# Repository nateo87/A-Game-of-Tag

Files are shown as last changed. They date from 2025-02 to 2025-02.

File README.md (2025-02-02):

# A Game of Tag
Here's the first genuine game project from David L Heiserman's 1978 book "How to Design & Build Your Own Custom TV Games". It's a very simple game where two player squares are moved around the screen. When one square touches another, both players disappear from the screen (it's up to you to decide who is "it"). Originally even less complex, I opted to add a little beep sound for when the tag occurs. The pitch of the beep can be set with a jumper on the upper-right side of the board.

It's easy for the player charcaters to fly off the screen - I recommend marking on your potentiometer knobs a sort of "starting position". Anyways, I encourage you to take a look into the book and tweak the designs. There's one addition the book recommends that would add "inertia" to the moving squares! Have fun, and please don't hesitate to reach out with questions.

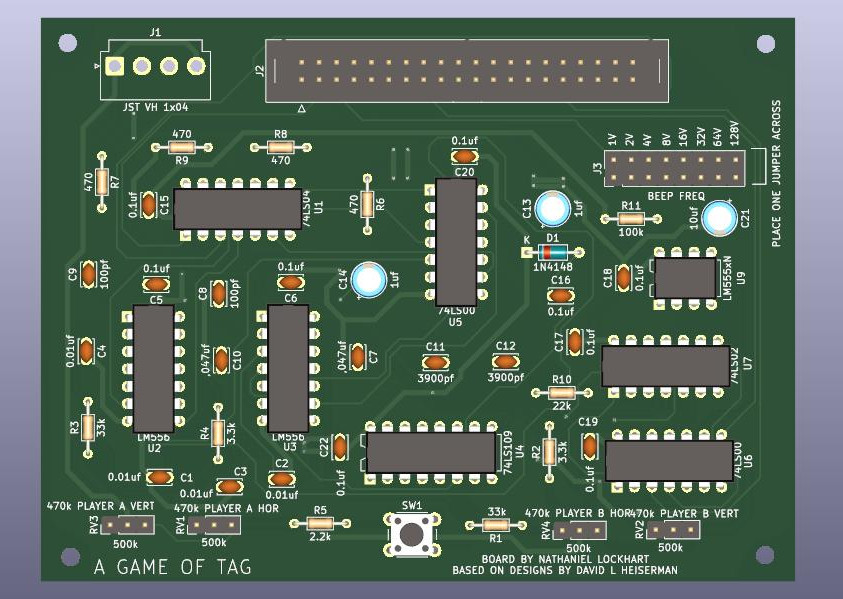
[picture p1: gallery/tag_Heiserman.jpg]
board render from KiCad


You can just solder wires directly from your player control pots to the PCB, or you can use pinheaders and have wires going from the pots with crimped on molex connectors at the other end. 

<b> BOM </b>

Caps:<br>
100pf x 2<br>
3900pf x 2<br>
10nf x 4<br>
47nf x 2<br>
0.1uf x 9<br>

Elec. Caps:<br>
1uf x 2<br>
10uf x 1<br>

Resistors:<br>
470ohm x 4<br>
2.2k x 1<br>
3.3k x 2<br>
22k x 1<br>
33k x 2<br>
100k x 1<br>

Potentiometers:<br>
500k x 4

Diode:<br>
1N4148 x 1

Switch:<br>
6x6mm tact switch x 1

Pin headers:<br>
2x20 IDC male, 2.54mm pitch<br>
2x8 pin header, 2.54mm pitch<br>
1x3 pin header, 2.54mm pitch x 4<br>

ICs:<br>
74LS00 x 2<br>
74LS02<br>
74LS04<br>
74LS109<br>
LM555<br>
LM556 x 2

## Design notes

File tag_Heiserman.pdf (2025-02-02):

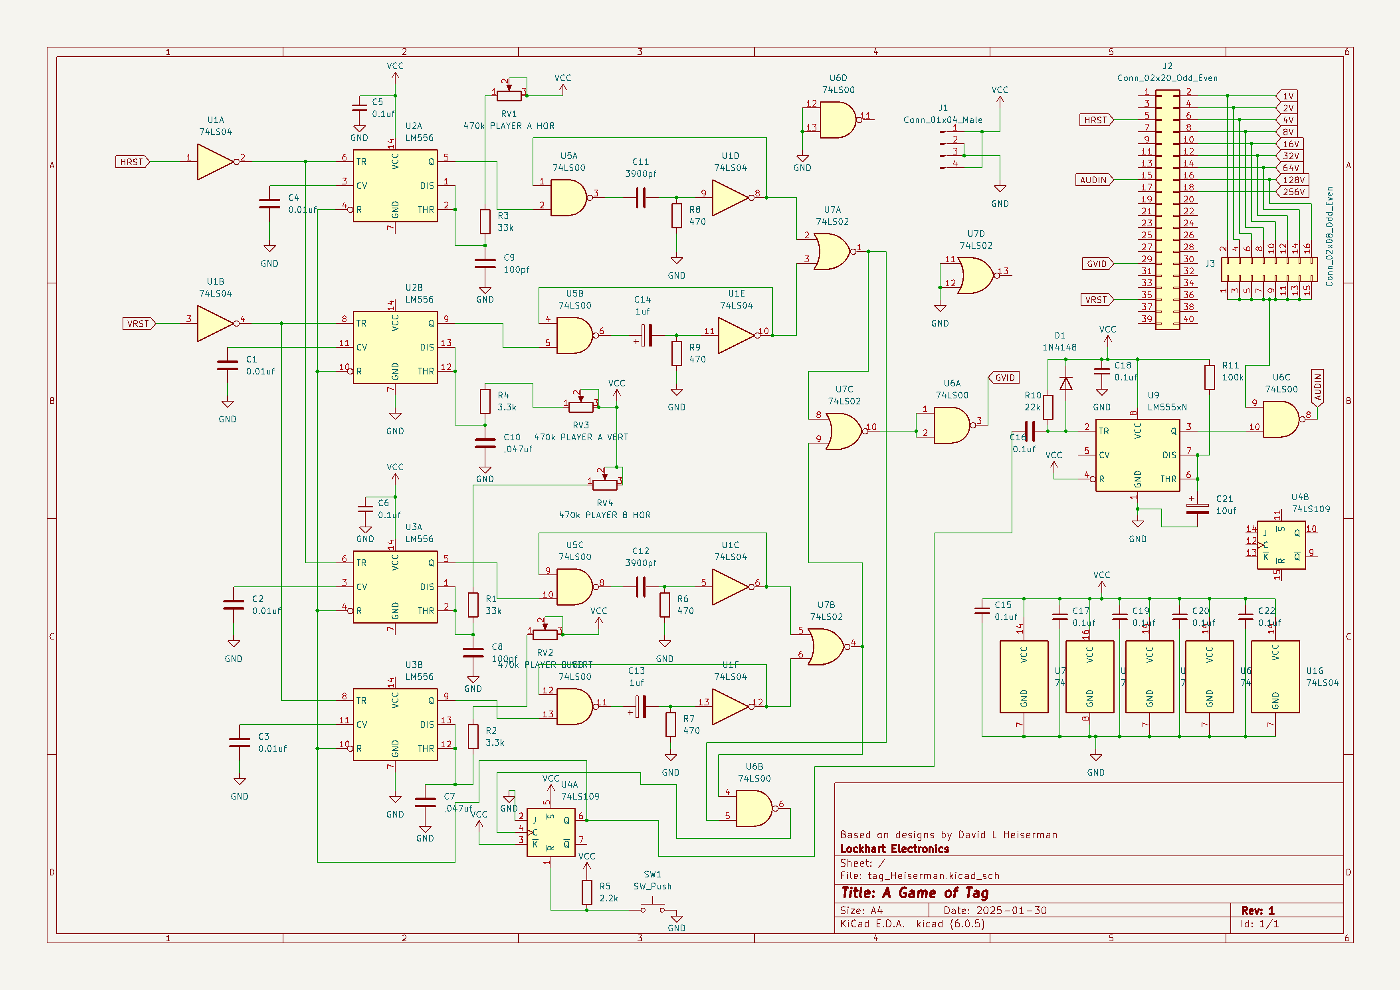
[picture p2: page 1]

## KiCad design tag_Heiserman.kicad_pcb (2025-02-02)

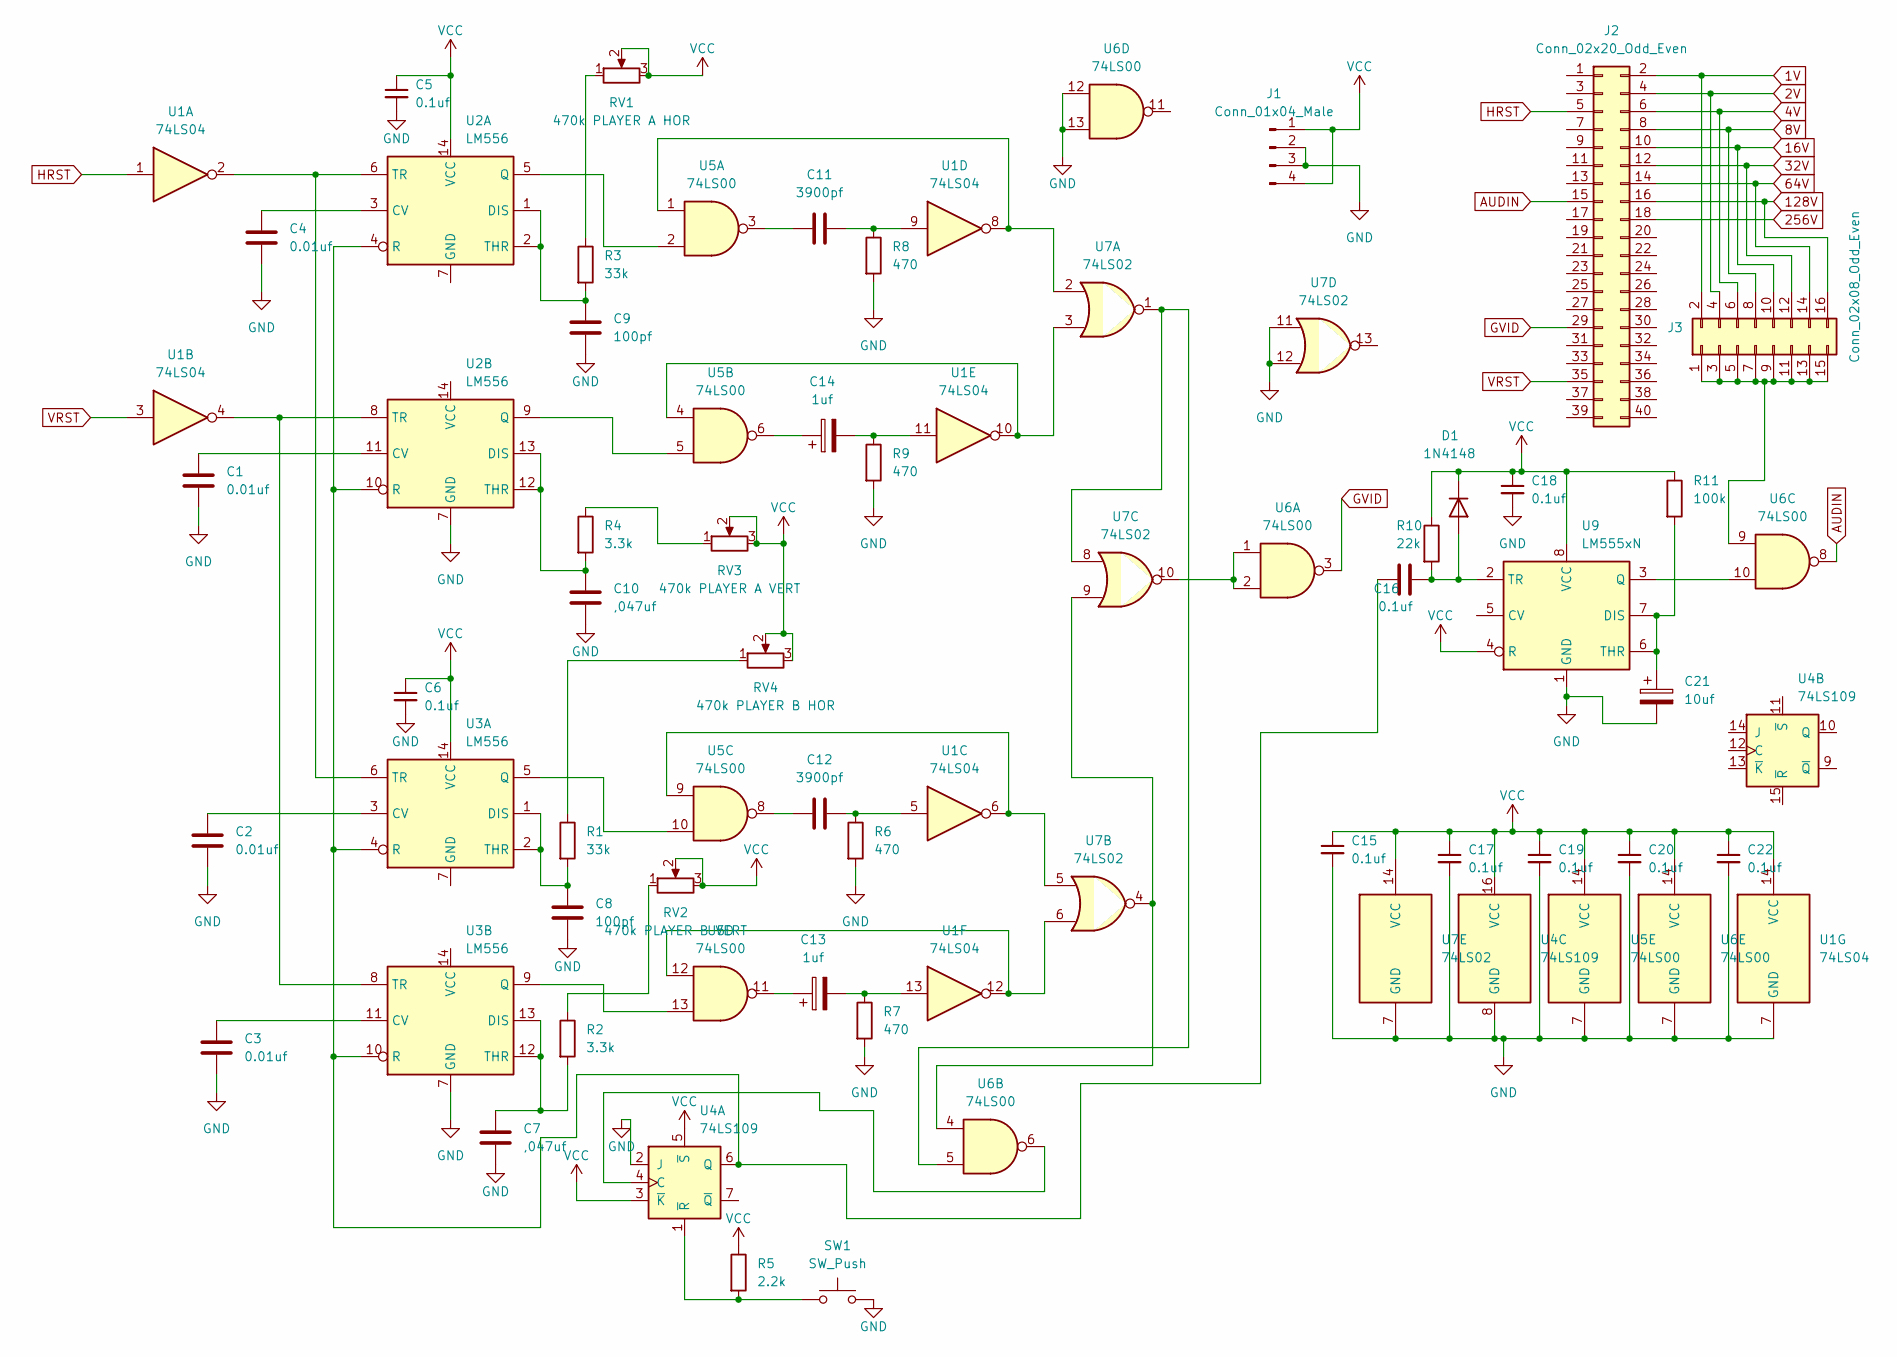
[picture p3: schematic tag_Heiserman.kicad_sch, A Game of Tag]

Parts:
C1, C2, C3, C4: 0.01uf; C_Disc_D3.4mm_W2.1mm_P2.50mm
C5, C6, C15, C16, C17, C18, C19, C20, C22: 0.1uf; C_Disc_D3.4mm_W2.1mm_P2.50mm
C7, C10: ,047uf; C_Disc_D3.4mm_W2.1mm_P2.50mm
C8, C9: 100pf; C_Disc_D3.4mm_W2.1mm_P2.50mm
C11, C12: 3900pf; C_Disc_D3.4mm_W2.1mm_P2.50mm
C13, C14: 1uf; CP_Radial_D5.0mm_P2.50mm
C21: 10uf; CP_Radial_D5.0mm_P2.50mm
D1: 1N4148; D_DO-35_SOD27_P7.62mm_Horizontal
J1: Conn_01x04_Male; JST_VH_B4P-VH-B_1x04_P3.96mm_Vertical
J2: Conn_02x20_Odd_Even; IDC-Header_2x20_P2.54mm_Vertical
J3: Conn_02x08_Odd_Even; PinHeader_2x08_P2.54mm_Vertical
R1, R3: 33k; R_Axial_DIN0204_L3.6mm_D1.6mm_P7.62mm_Horizontal
R2, R4: 3.3k; R_Axial_DIN0204_L3.6mm_D1.6mm_P7.62mm_Horizontal
R5: 2.2k; R_Axial_DIN0204_L3.6mm_D1.6mm_P7.62mm_Horizontal
R6, R7, R8, R9: 470; R_Axial_DIN0204_L3.6mm_D1.6mm_P7.62mm_Horizontal
R10: 22k; R_Axial_DIN0204_L3.6mm_D1.6mm_P7.62mm_Horizontal
R11: 100k; R_Axial_DIN0204_L3.6mm_D1.6mm_P7.62mm_Horizontal
RV1: 470k PLAYER A HOR; PinHeader_1x03_P2.54mm_Vertical
RV2: 470k PLAYER B VERT; PinHeader_1x03_P2.54mm_Vertical
RV3: 470k PLAYER A VERT; PinHeader_1x03_P2.54mm_Vertical
RV4: 470k PLAYER B HOR; PinHeader_1x03_P2.54mm_Vertical
SW1: SW_Push; SW_PUSH_6mm
U1: 74LS04; DIP-14_W7.62mm
U2, U3: LM556; DIP-14_W7.62mm
U4: 74LS109; DIP-16_W7.62mm
U5, U6: 74LS00; DIP-14_W7.62mm
U7: 74LS02; DIP-14_W7.62mm
U9: LM555xN; DIP-8_W7.62mm

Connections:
1V: J2.2, J3.2
2V: J2.4, J3.4
4V: J2.6, J3.6
8V: J2.8, J3.8
16V: J2.10, J3.10
32V: J2.12, J3.12
64V: J2.14, J3.14
128V: J2.16, J3.16
256V: J2.18
AUDIN: J2.15, U6.8
GND: C1.2, C2.2, C3.2, C4.2, C5.2, C6.2, C7.2, C8.2, C9.2, C10.2, C15.2, C17.2, C18.2, C19.2, C20.2, C21.2, C22.2, J1.2, J1.3, R6.2, R7.2, R8.2, R9.2, SW1.2, U1.7 (GND), U2.7 (GND), U3.7 (GND), U4.2 (J), U4.8 (GND), U5.7 (GND), U6.7 (GND), U6.12, U6.13, U7.7 (GND), U7.11, U7.12, U9.1 (GND)
GVID: J2.29, U6.3
HRST: J2.5, U1.1
unnamed: C1.1, U2.11 (CV)
unnamed: C2.1, U3.3 (CV)
unnamed: C3.1, U3.11 (CV)
unnamed: C4.1, U2.3 (CV)
unnamed: C7.1, R2.2, U3.12 (THR), U3.13 (DIS)
unnamed: C8.1, R1.2, U3.1 (DIS), U3.2 (THR)
unnamed: C9.1, R3.2, U2.1 (DIS), U2.2 (THR)
unnamed: C10.1, R4.2, U2.12 (THR), U2.13 (DIS)
unnamed: C11.1, R8.1, U1.9
unnamed: C11.2, U5.3
unnamed: C12.1, R6.1, U1.5
unnamed: C12.2, U5.8
unnamed: C13.1, U5.11
unnamed: C13.2, R7.1, U1.13
unnamed: C14.1, U5.6
unnamed: C14.2, R9.1, U1.11
unnamed: C16.1, D1.2 (A), R10.2, U9.2 (TR)
unnamed: C16.2, U2.4 (R), U2.10 (R), U3.4 (R), U3.10 (R), U4.6 (Q)
unnamed: C21.1, R11.2, U9.6 (THR), U9.7 (DIS)
unnamed: J3.1, J3.3, J3.5, J3.7, J3.9, J3.11, J3.13, J3.15, U6.9
unnamed: R1.1, RV4.1
unnamed: R2.1, RV2.1
unnamed: R3.1, RV1.1
unnamed: R4.1, RV3.1
unnamed: R5.2, SW1.1, U4.1 (~R)
unnamed: U1.2, U2.6 (TR), U3.6 (TR)
unnamed: U1.4, U2.8 (TR), U3.8 (TR)
unnamed: U1.6, U5.9, U7.5
unnamed: U1.8, U5.1, U7.2
unnamed: U1.10, U5.4, U7.3
unnamed: U1.12, U5.12, U7.6
unnamed: U2.5 (Q), U5.2
unnamed: U2.9 (Q), U5.5
unnamed: U3.5 (Q), U5.10
unnamed: U3.9 (Q), U5.13
unnamed: U4.4 (C), U6.6
unnamed: U6.1, U6.2, U7.10
unnamed: U6.4, U7.4, U7.9
unnamed: U6.5, U7.1, U7.8
unnamed: U6.10, U9.3 (Q)
VCC: C5.1, C6.1, C15.1, C17.1, C18.1, C19.1, C20.1, C22.1, D1.1 (K), J1.1, J1.4, R5.1, R10.1, R11.1, RV1.2, RV1.3, RV2.2, RV2.3, RV3.2, RV3.3, RV4.2, RV4.3, U1.14 (VCC), U2.14 (VCC), U3.14 (VCC), U4.3 (~K), U4.5 (~S), U4.16 (VCC), U5.14 (VCC), U6.14 (VCC), U7.14 (VCC), U9.4 (R), U9.8 (VCC)
VRST: J2.35, U1.3

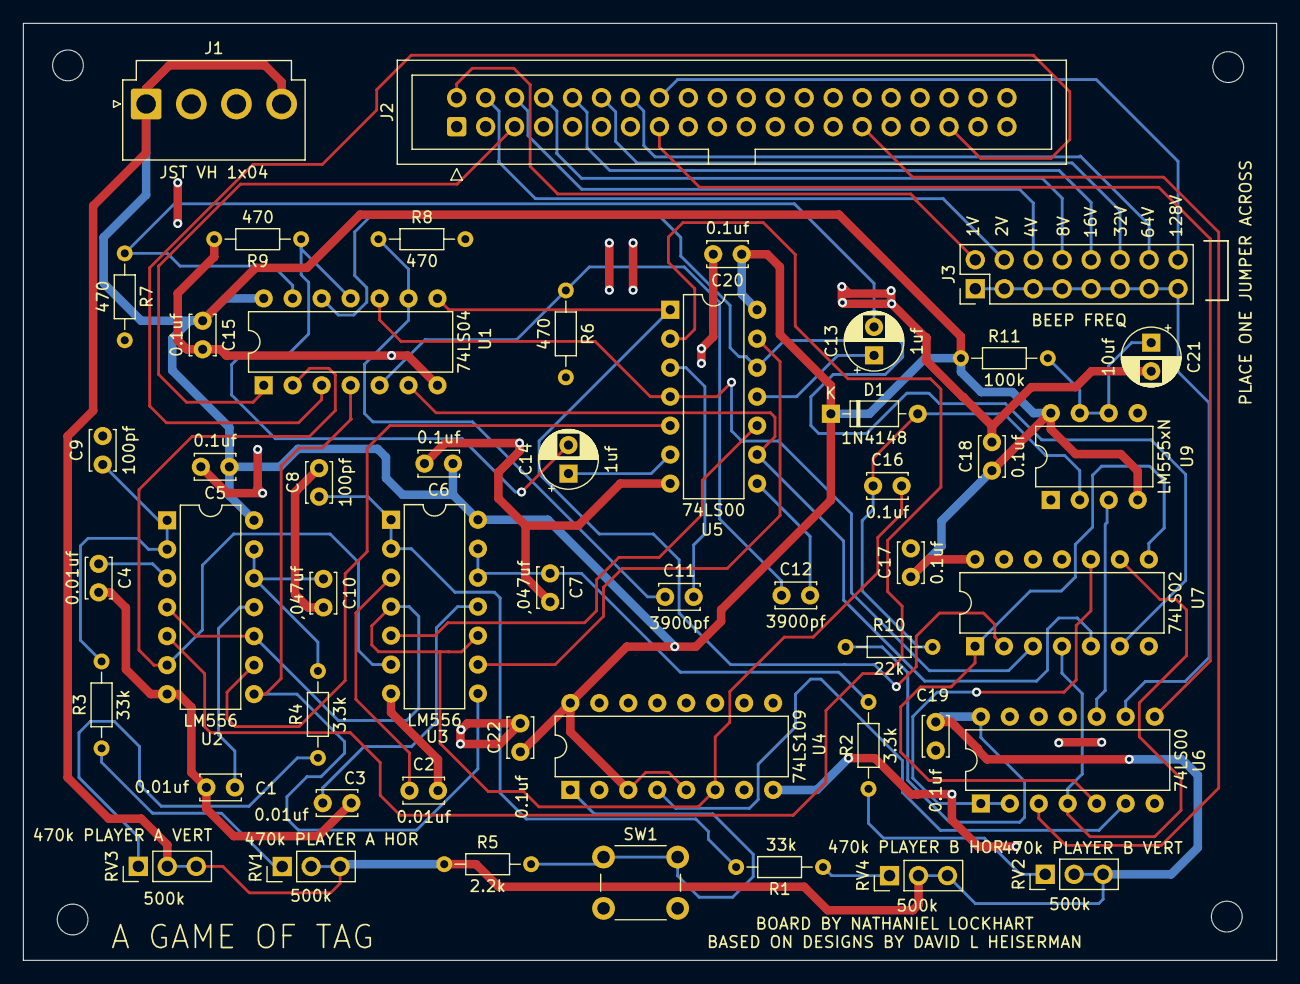
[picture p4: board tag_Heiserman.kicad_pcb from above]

Board: 2 copper layers, 109.9 x 82.2 mm, 50 parts (0 on the bottom side), 54 nets.
